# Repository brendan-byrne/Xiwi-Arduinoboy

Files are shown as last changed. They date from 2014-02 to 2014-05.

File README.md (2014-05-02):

## Arduinoboy - Xiwi Electronics ##

Product Page - <a href="http://xiwielectronics.com/products/arduinoboy">http://tiny.cc/gdzcbx</a><br />
Arduinoboy Google Code Page -  <a href="tiny.cc/bkz4xw">tiny.cc/bkz4xw</a>

Based on the Arduino platform, this device allows for MIDI signals to be sent and received by software such as Nanoloop, LSDJ, and mGB running on the Nintendo Gameboy.

Arduinoboy was developed and released under the GNU General Public License by Timothy Lamb in fall of 2008.



# Files #
**Arduinoboy Code** : Contains the original AB code written by Timothy Lamb. Upload/access via Arduino<br />

**Eagle Files** : Contains Eagle PCB and Schematic files for Xiwi Electronics Arduinoboy.<br />

**AB Editor - MIDI** : Max/MSP patch for altering MIDI channel information on the Arduinoboy. Requires MIDI In and Out ports on Arduinoboy.

**AB Enclosure** : Contains Adobe Illustrator vector drawing of Arduinoboy enclosure. Use file with laser cutter to fabricate enclosure.

**Arduino Boy Kit Assembly Instructions** : Instructions for assembling the kit sold through Xiwi Electronics. <a href="http://xiwielectronics.com/products/arduinoboy-kit">http://tiny.cc/5bzcbx</a>

**Bill of Materials** : All components and hardware used in construction of Xiwi Arduinoboy. Contains product numbers mostly through Mouser.

**Operational Document** : Layout of Xiwi Arduinoboy operations.

**mGB1_3_0.gb** : ROM file for mGB. Upload to Gameboy flash cartridge. Can receive MIDI note information to access Gameboy's internal synthesis chips. More documentation on Google Code page.

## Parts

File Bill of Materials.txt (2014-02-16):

#	Item		Mouser Part # / URL	Notes
----------------------------------------------------------------------------
1	ATMEGA328P	556-ATMEGA328P-PU	Burn Bootloader. Flash chip
1	6N138		859-6N138
	
1	28-pin Socket	571-1-390262-2		
1 	8-pin Socket	571-1825093-2

1	16 Mhz Crystal	559-FOXS160-20-LF
1	7805 V Reg	863-NCP7805TG

1 	1N914 Diode	512-1N914		Can be most any small signal diode

2	220 Resistor	291-220-RC
1	270 Resistor	291-270-RC
1	4.7K Resistor	291-4.7K-RC
1	2k Resistor	291-2K-RC		Pull-down Resistor. 1K+ Value
6	2.2K Resistor	291-2.2K-RC		LED Brightness. Personal Preference

6 	3mm LEDs	604-WP3A8GD		Any color

1 	1uf Capacitor	661-EKMA500ETC1R0MD0
2	22pf Capacitor	140-50N2-220J-RC

3 	MIDI Jacks	161-0504-E
1	2.1mm Jack	502-RAPC722X
1	Pushbutton	URL - bit.ly/1naxZhZ	Change Laser file to fit your button

1	MIDI Plug	171-0275
1 	DMG Link Cable	URL - bit.ly/MtgLkj

4	1/4" 4-40 Flat	URL - bit.ly/Mtf0ne	Screws for Bottomplate
4 	3/8" 4-40 Flat	URL - bit.ly/Mtf0ne	Screws for Faceplate
4	Hex Nut 4-40	URL - bit.ly/1eUcsFM	Btwn Faceplate and PCB
4	Hex Standoff	761-2108T-440-AL-7

4 	Rubber Feet	URL - bit.ly/1isiEZS

1  	Xiwi Arduinoboy PCB
1  	Xiwi Acrylic Arduinoboy Faceplate
1  	Xiwi Acrylic Arduinoboy Bottomplate

820 Ohm - Orange
10k Ohm - Blue
2K Ohm - Green

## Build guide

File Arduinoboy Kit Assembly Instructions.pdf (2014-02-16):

Arduinoboy Kit Assembly Instructions Brendan Byrne – Xiwi Electronics
GitHub Repository - http://tiny.cc/uyscbx
Product Page - http://tiny.cc/potcbx **************************************************************

Hello and thank you for purchasing an Arduinoboy kit from Xiwi Electronics. Follow the instructions listed below and you'll be making chiptunes in no time at all. Enjoy, friend.

This kit assumes you have introductory knowledge of electronic components and soldering. At the very least, you will need a soldering iron, solder, wire strippers, flush cutters, helpy hands, pliers, and Phillips head screwdriver.

It is recommended that you reference this doc from a computer rather than printing.

For more detailed information such as PCB layout, laser cutter files, and schematics, please refer to the GitHub Link at the top of this document.

For questions or problems related to the Arduinoboy Kit you may contact me, Brendan Byrne, at xiwicontact@gmail.com. I'll do everything I can to make sure you have a fully operational unit.

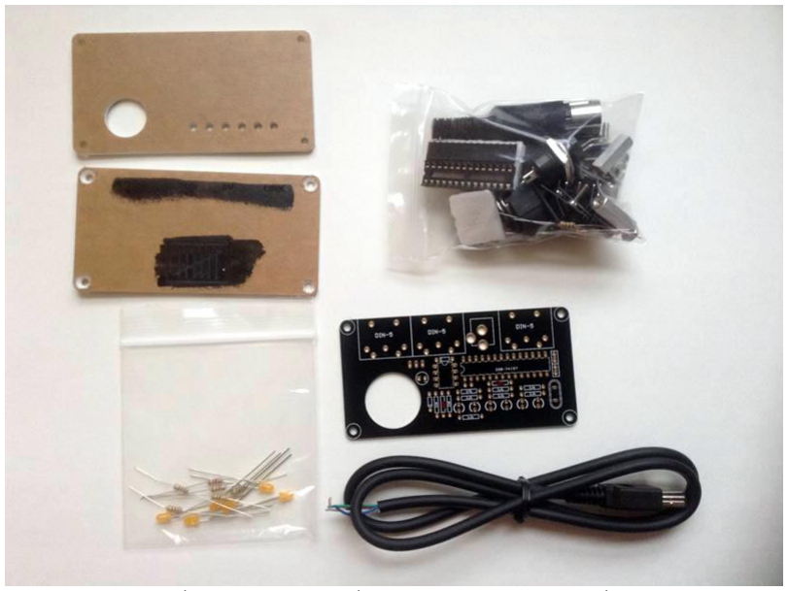
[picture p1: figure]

(Loose black wire and operational document not pictured)

Bill of Materials
**************************************************************

Main Bag:
1 – ATMEGA328 – Flashed with AB Software
1 – 6N138 Optoisolator
1 – 28 pin IC Socket
1 – 8 pin IC Socket
1 – 7805 Voltage Regulator
1 – 16 Mhz Crystal
2 – 220 Ohm Resistors (Red-Red-Brown)
1 – 4.7k Ohm Resistor (Yellow-Purple-Red) 1 – 5.6k Ohm Resistor (Green-Blue-Red) 1 – 270 Ohm Resistor (Blue one)
2 – 1N914 Diodes
1 – 1uF Capacitor
2 – 22pF Capacitors
1 – Pushbutton
3 – MIDI Connector Panel Jacks
1 – MIDI Plug
1 – 2.1mm Barrel Jack
4 – 1/4” 4-40 Flat Head Machine Screws 4 – 3/8” 4-40 Flat Head Machine Screws 4 - 4-40 Hex Nuts
4 – 25/32” Zinc Standoffs
4 – Rubber Feet

LED Bag:
6 – 3mm LEDs of Your Chosen Color
6 – Corresponding Resistors
Red | - 2k Ohm (Red-Black-Red)
Blue | - 10k Ohm (Brown-Black-Orange)
Green | - 1.2k Ohm (Brown-Red-Red)
Orange | - 820 Ohm (Grey-Red-Brown)

Loose:
1 – Arduinoboy PCB
1 – Acrylic Faceplate
1 – Acrylic Bottomplate
1 – Half of Original Gameboy DMG Link Cable 1 – Loose Black Wire
1 – Operational Document

PCB and Faceplate Assembly **************************************************************

The board is labeled with the values of resistors and their corresponding locations. However, there are two mistakes. I apologize. These locations have been marked with a red sharpie. The position marked 270 will take the 4.7k Ohm resistor and the one marked 2k will receive the 5.6k Ohm resistor. Make sure your board resembles the one pictured below.

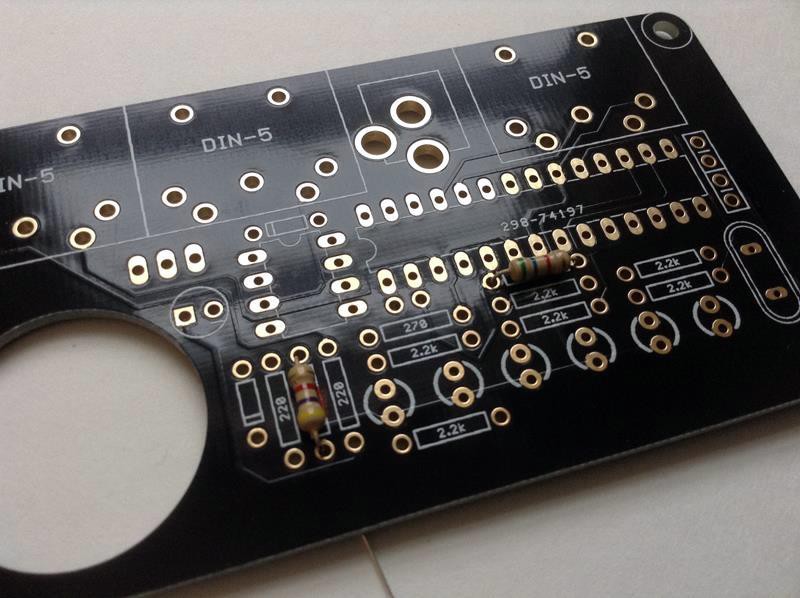
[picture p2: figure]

Following this step. You may proceed with populating the circuit board with the rest of the low level components (i.e., resistors, diodes, and the 16 Mhz crystal). The location marked “270” receives the blue resistor.

Take note that wherever you see a “2.2k” label, this is where you will place the resistors from the LED bag. In this example, I am building an orange Arduinoboy and am using 820 Ohm resistor.

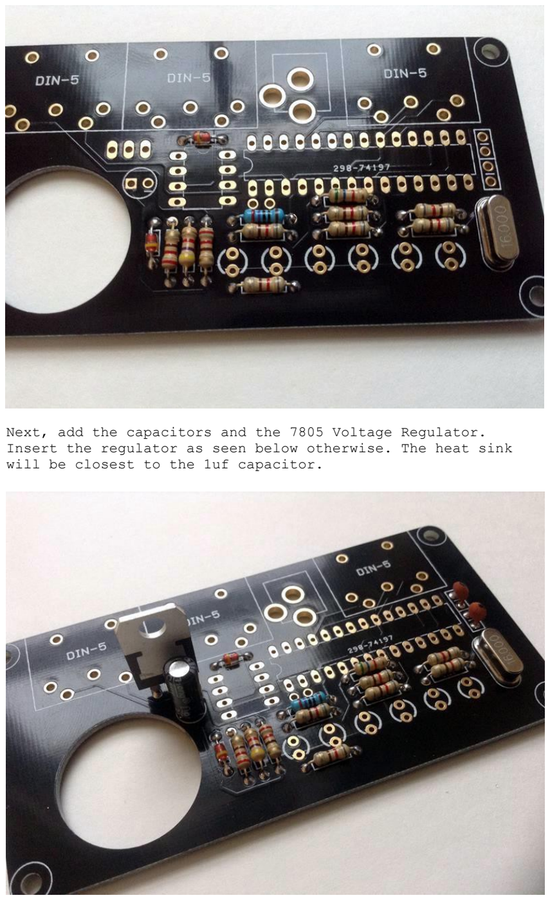
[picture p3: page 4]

Next, add the capacitors and the 7805 Voltage Regulator. Insert the regulator as seen below otherwise. The heat sink will be closest to the 1uf capacitor.

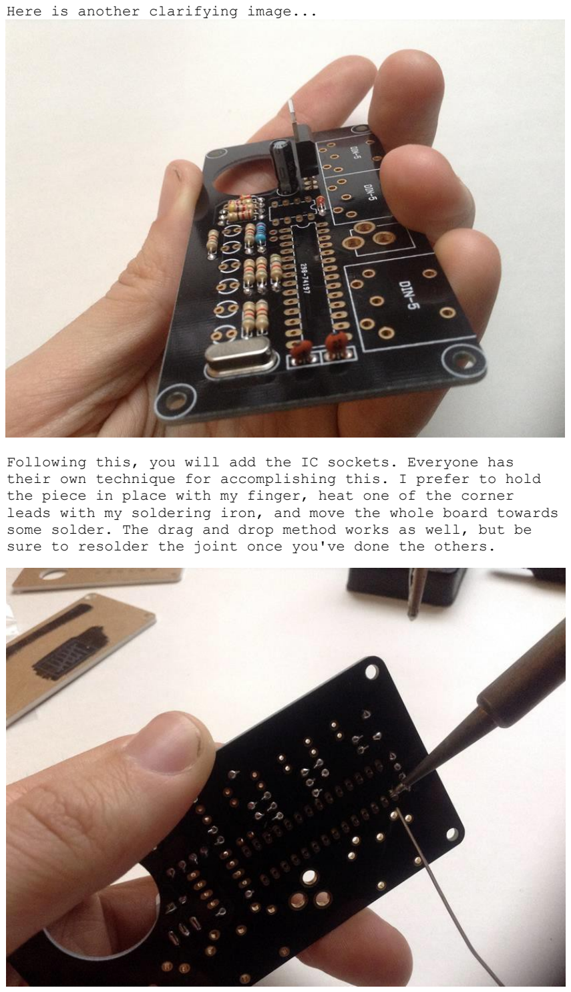
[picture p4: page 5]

Here is another clarifying image...

Following this, you will add the IC sockets. Everyone has their own technique for accomplishing this. I prefer to hold the piece in place with my finger, heat one of the corner leads with my soldering iron, and move the whole board towards some solder. The drag and drop method works as well, but be sure to resolder the joint once you've done the others.

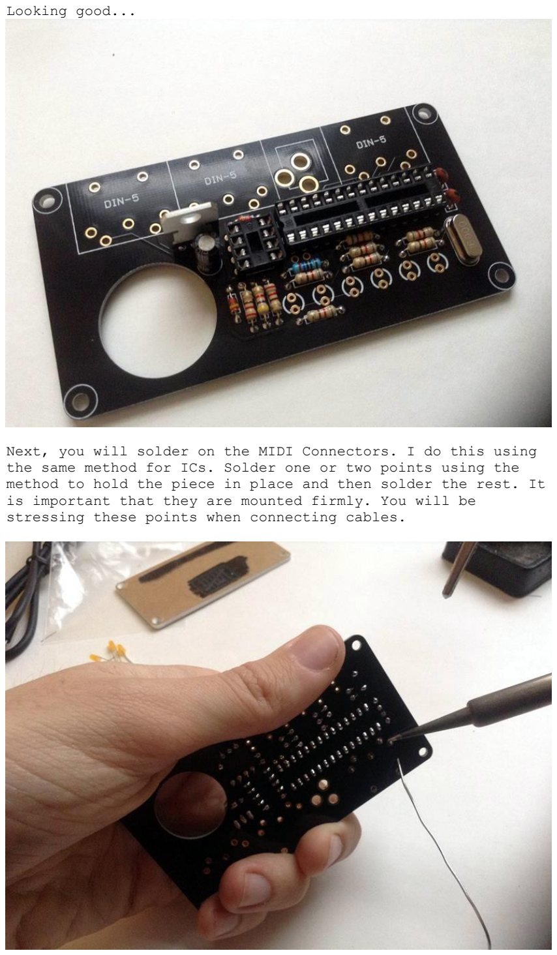
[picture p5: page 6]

Looking good...

Next, you will solder on the MIDI Connectors. I do this using the same method for ICs. Solder one or two points using the method to hold the piece in place and then solder the rest. It is important that they are mounted firmly. You will be stressing these points when connecting cables.

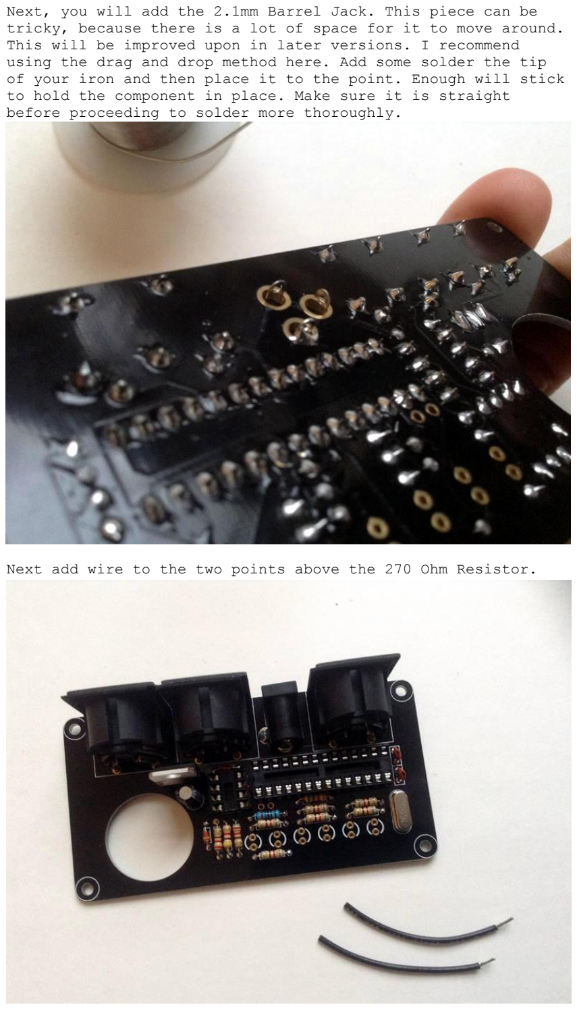
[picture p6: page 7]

Next, you will add the 2.1mm Barrel Jack. This piece can be tricky, because there is a lot of space for it to move around. This will be improved upon in later versions. I recommend using the drag and drop method here. Add some solder the tip of your iron and then place it to the point. Enough will stick to hold the component in place. Make sure it is straight before proceeding to solder more thoroughly.

Next add wire to the two points above the 270 Ohm Resistor.

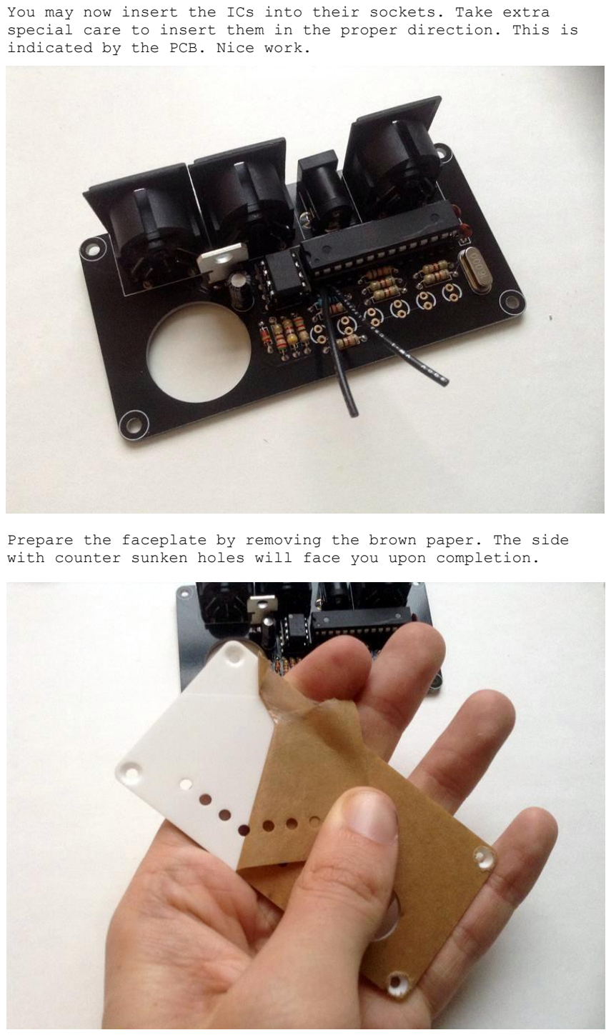
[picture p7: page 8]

You may now insert the ICs into their sockets. Take extra special care to insert them in the proper direction. This is indicated by the PCB. Nice work.

Prepare the faceplate by removing the brown paper. The side with counter sunken holes will face you upon completion.

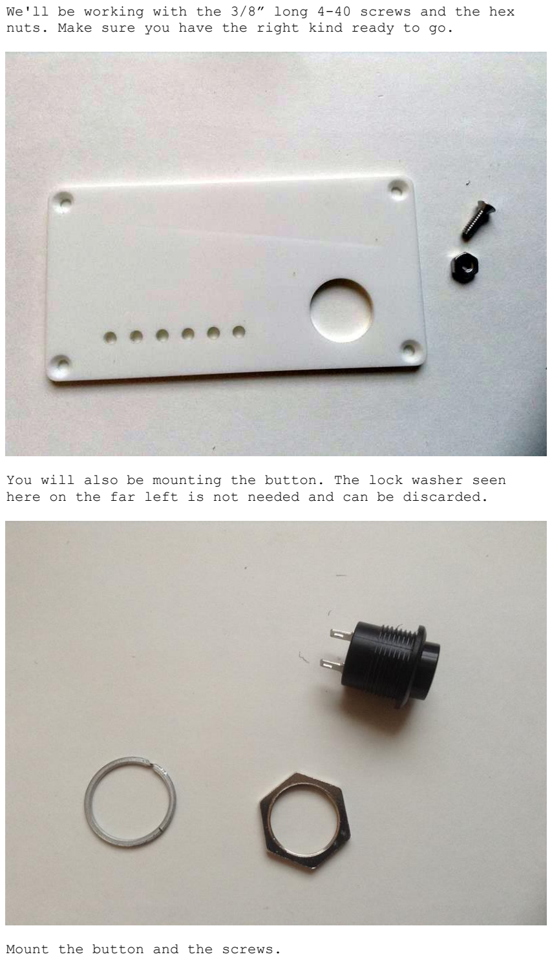
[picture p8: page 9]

We'll be working with the 3/8” long 4-40 screws and the hex nuts. Make sure you have the right kind ready to go.

You will also be mounting the button. The lock washer seen here on the far left is not needed and can be discarded.

Mount the button and the screws.

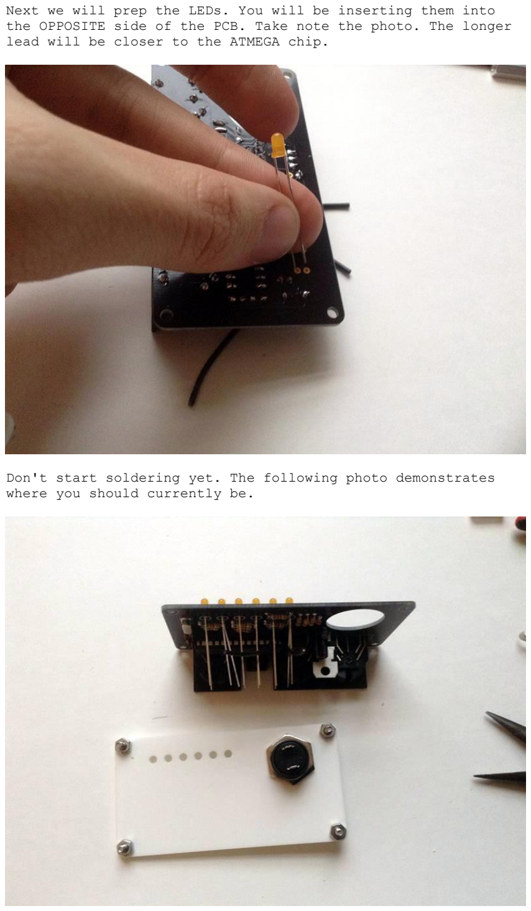
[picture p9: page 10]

Next we will prep the LEDs. You will be inserting them into the OPPOSITE side of the PCB. Take note the photo. The longer lead will be closer to the ATMEGA chip.

Don't start soldering yet. The following photo demonstrates where you should currently be.

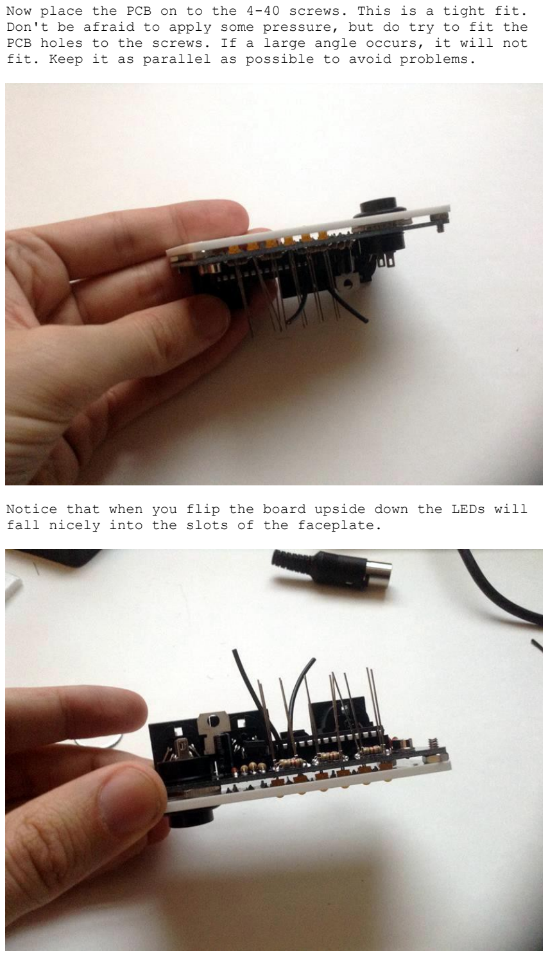
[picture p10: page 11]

Now place the PCB on to the 4-40 screws. This is a tight fit. Don't be afraid to apply some pressure, but do try to fit the PCB holes to the screws. If a large angle occurs, it will not fit. Keep it as parallel as possible to avoid problems.

Notice that when you flip the board upside down the LEDs will fall nicely into the slots of the faceplate.

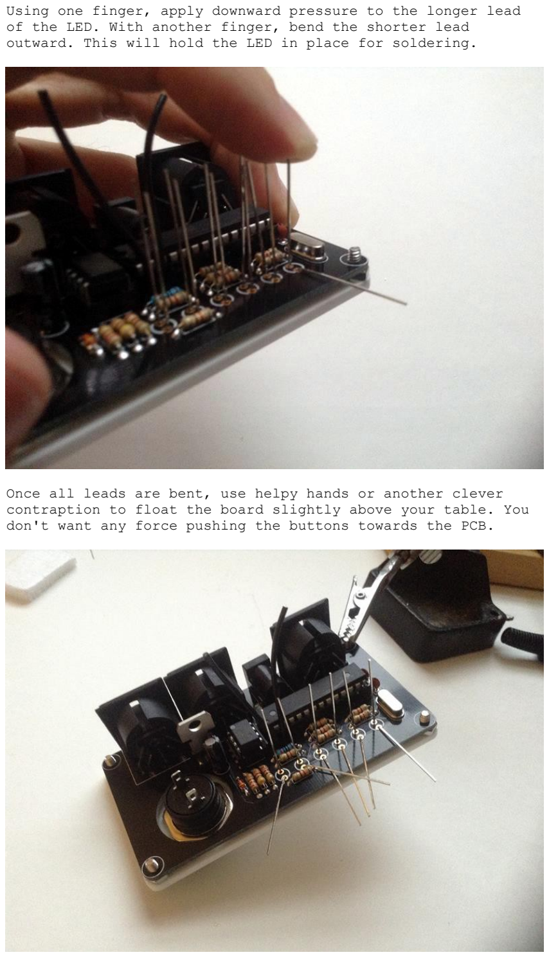
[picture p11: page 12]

Using one finger, apply downward pressure to the longer lead of the LED. With another finger, bend the shorter lead outward. This will hold the LED in place for soldering.

Once all leads are bent, use helpy hands or another clever contraption to float the board slightly above your table. You don't want any force pushing the buttons towards the PCB.

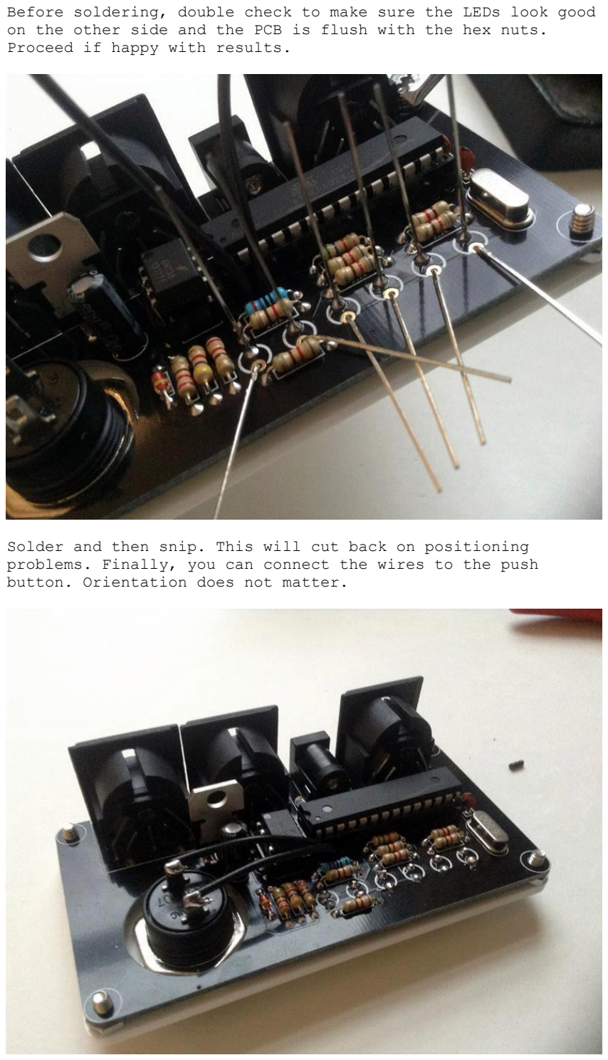
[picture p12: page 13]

Before soldering, double check to make sure the LEDs look good on the other side and the PCB is flush with the hex nuts. Proceed if happy with results.

Solder and then snip. This will cut back on positioning problems. Finally, you can connect the wires to the push button. Orientation does not matter.

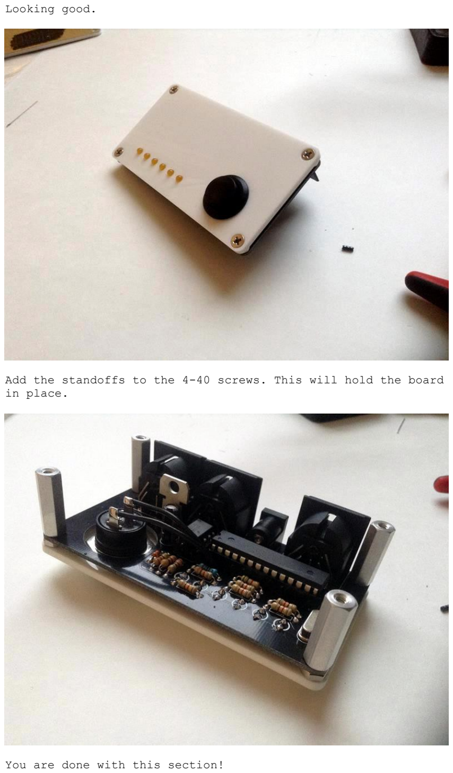
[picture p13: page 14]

Looking good.

Add the standoffs to the 4-40 screws. This will hold the board in place.

You are done with this section!

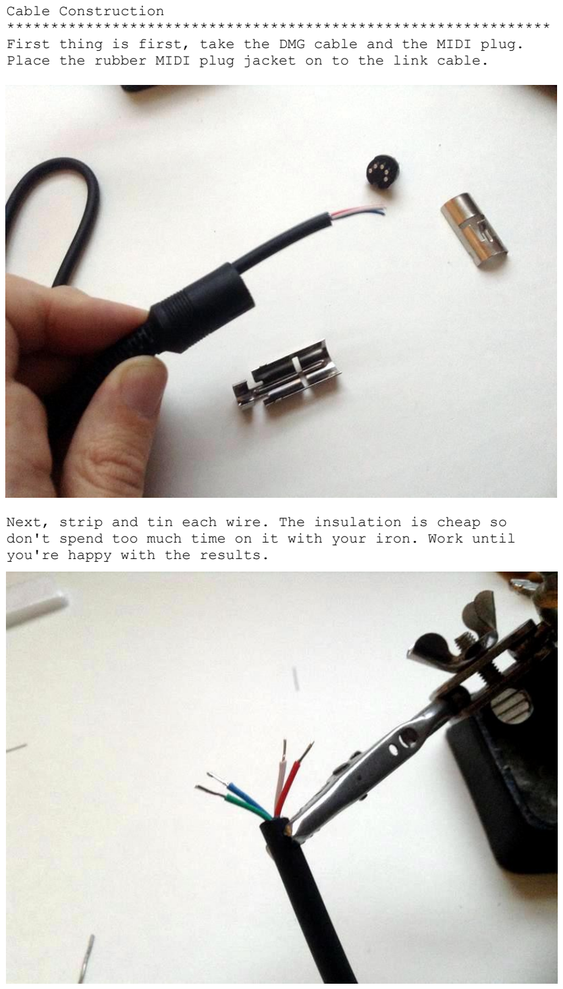
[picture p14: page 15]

Cable Construction
************************************************************** First thing is first, take the DMG cable and the MIDI plug. Place the rubber MIDI plug jacket on to the link cable.

Next, strip and tin each wire. The insulation is cheap so don't spend too much time on it with your iron. Work until you're happy with the results.

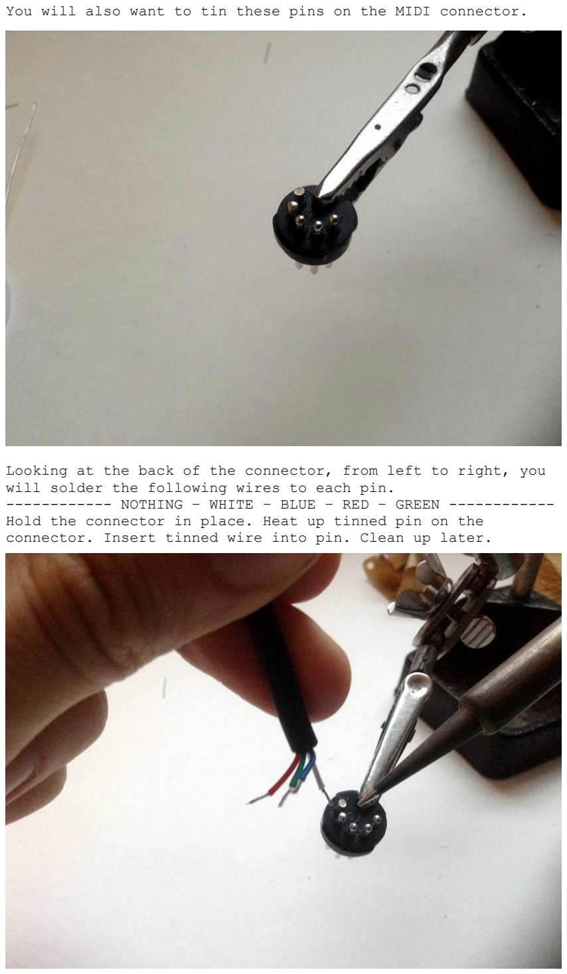
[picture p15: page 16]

You will also want to tin these pins on the MIDI connector.

Looking at the back of the connector, from left to right, you will solder the following wires to each pin.
------------ NOTHING – WHITE – BLUE – RED – GREEN ------------Hold the connector in place. Heat up tinned pin on the connector. Insert tinned wire into pin. Clean up later.

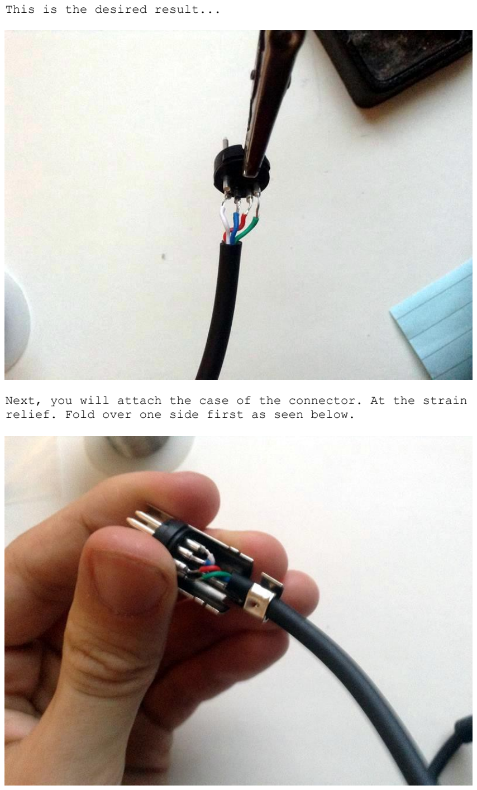
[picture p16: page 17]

This is the desired result...

Next, you will attach the case of the connector. At the strain relief. Fold over one side first as seen below.

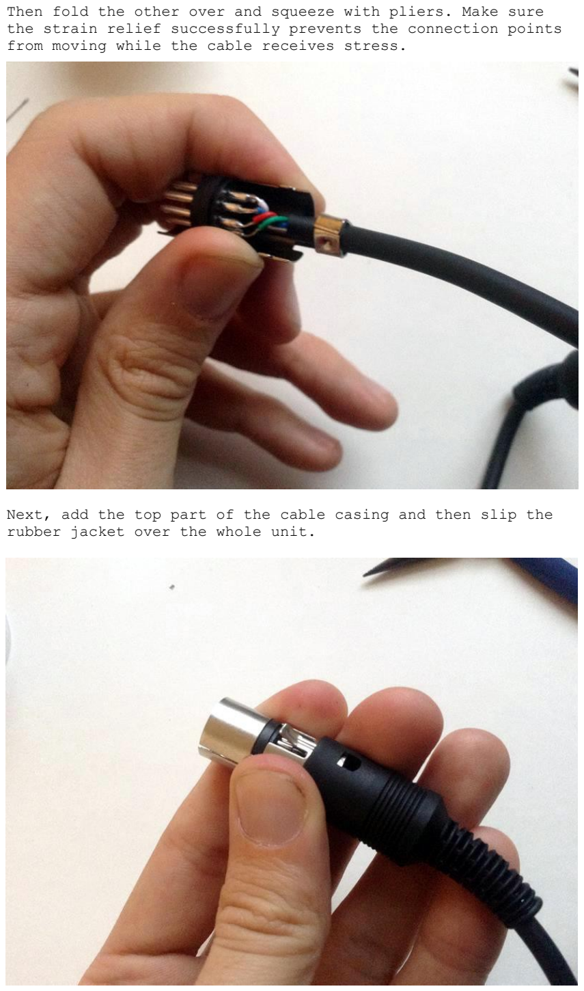
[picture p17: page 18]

Then fold the other over and squeeze with pliers. Make sure the strain relief successfully prevents the connection points from moving while the cable receives stress.

Next, add the top part of the cable casing and then slip the rubber jacket over the whole unit.

You've completed this portion!

At this point it is recommended that you power on your Arduinoboy and connect it to your Gameboy. Run some test MIDI information into or out of it and see if it is working properly. Refer to the Arduinoboy documentation on the Google code page for proper operation code.google.com/p/arduinoboy/

If you suspect your Arduinoboy isn't functioning properly, return to the circuit and perform basic troubleshooting to discover the problem. You may also want to refer to a schematic and the board layout. These can be found on the GitHub page. http://tiny.cc/uyscbx

If it's working properly, then proceed with instructions...

************************************************************** Finishing Touches
************************************************************** Remove the protective paper from the acrylic bottomplate. You can use your fingernail to remove the small pieces of paper without fear of damaging or scratching the surface.

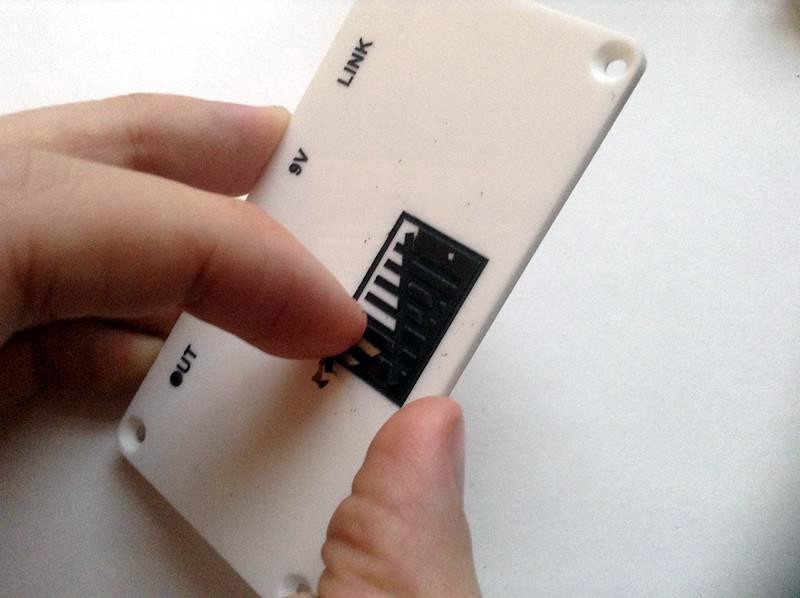
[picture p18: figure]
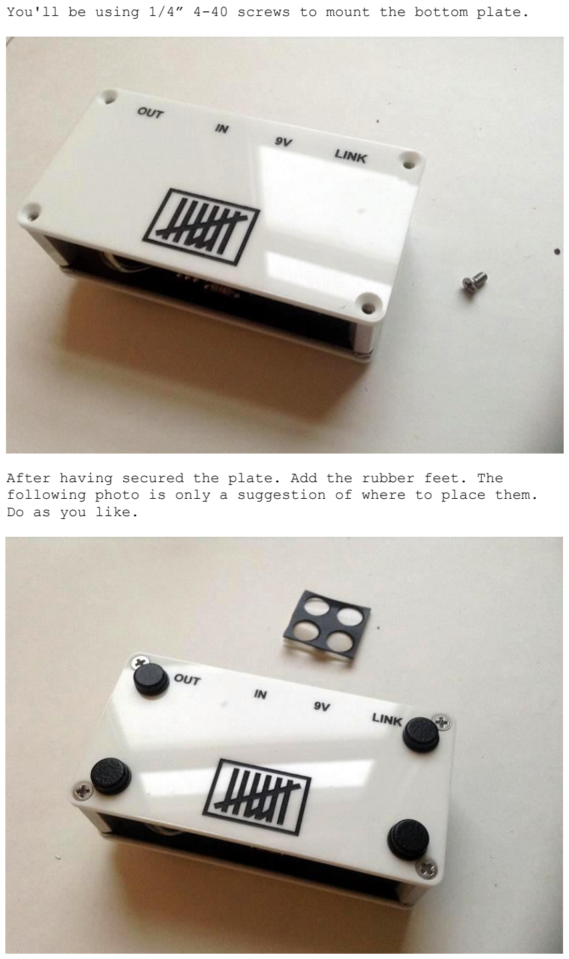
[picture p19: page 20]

You'll be using 1/4” 4-40 screws to mount the bottom plate.

After having secured the plate. Add the rubber feet. The following photo is only a suggestion of where to place them. Do as you like.

Congratulations. You are now the proud owner of a totally awesome device for making killer music and you built it yourself. High five!

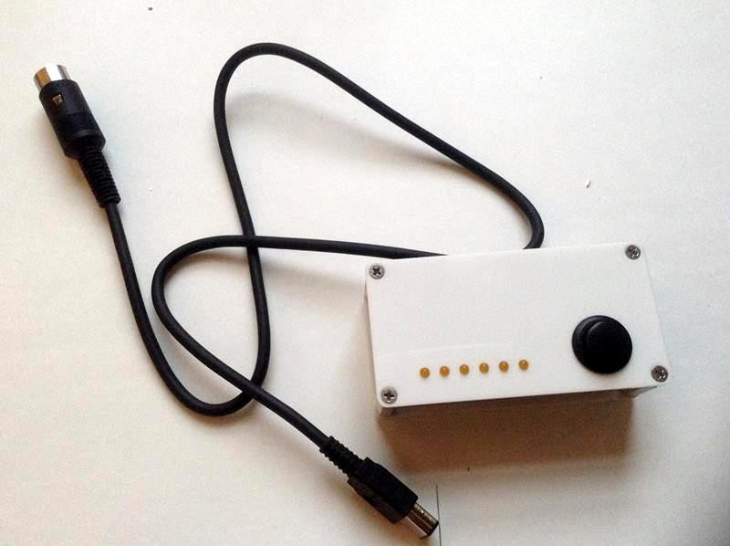
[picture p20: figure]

Thank you.

Follow me on...
twitter - @bigwetdognose (https://twitter.com/bigwetdognose)
tumblr – wtfbyrne.tumlblr.com (http://wtfbyrne.tumblr.com/)

Send chip jams/photos of your AB. Will retweet.

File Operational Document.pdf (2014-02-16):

# Arduinoboy from Xiwi Electronics

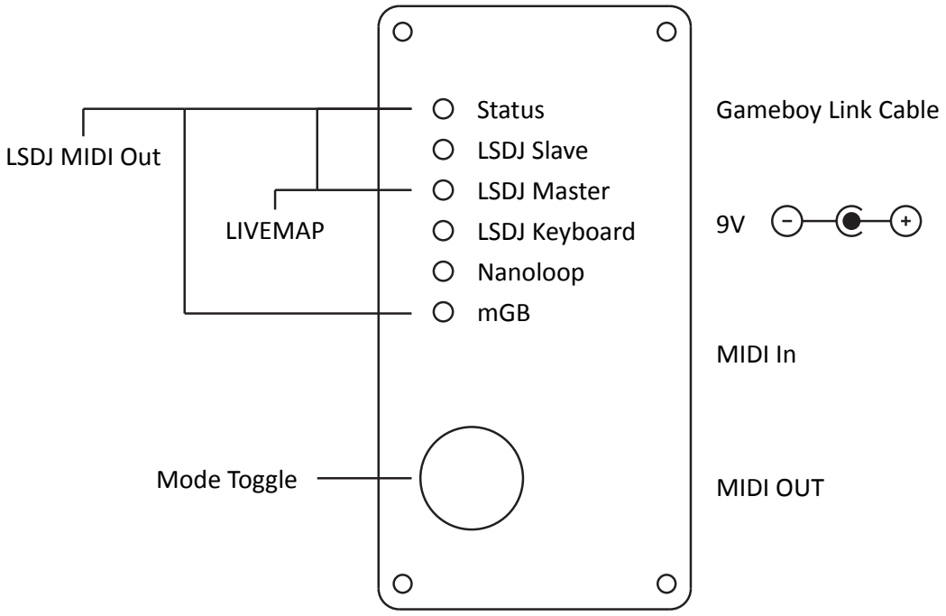
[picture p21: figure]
Status; Gameboy Link Cable; MIDI In; MIDI OUT; LSDJ Slave; Nanoloop mGB; LSDJ Master; LIVEMAP; LSDJ Keyboard; LSDJ MIDI Out; Mode Toggle

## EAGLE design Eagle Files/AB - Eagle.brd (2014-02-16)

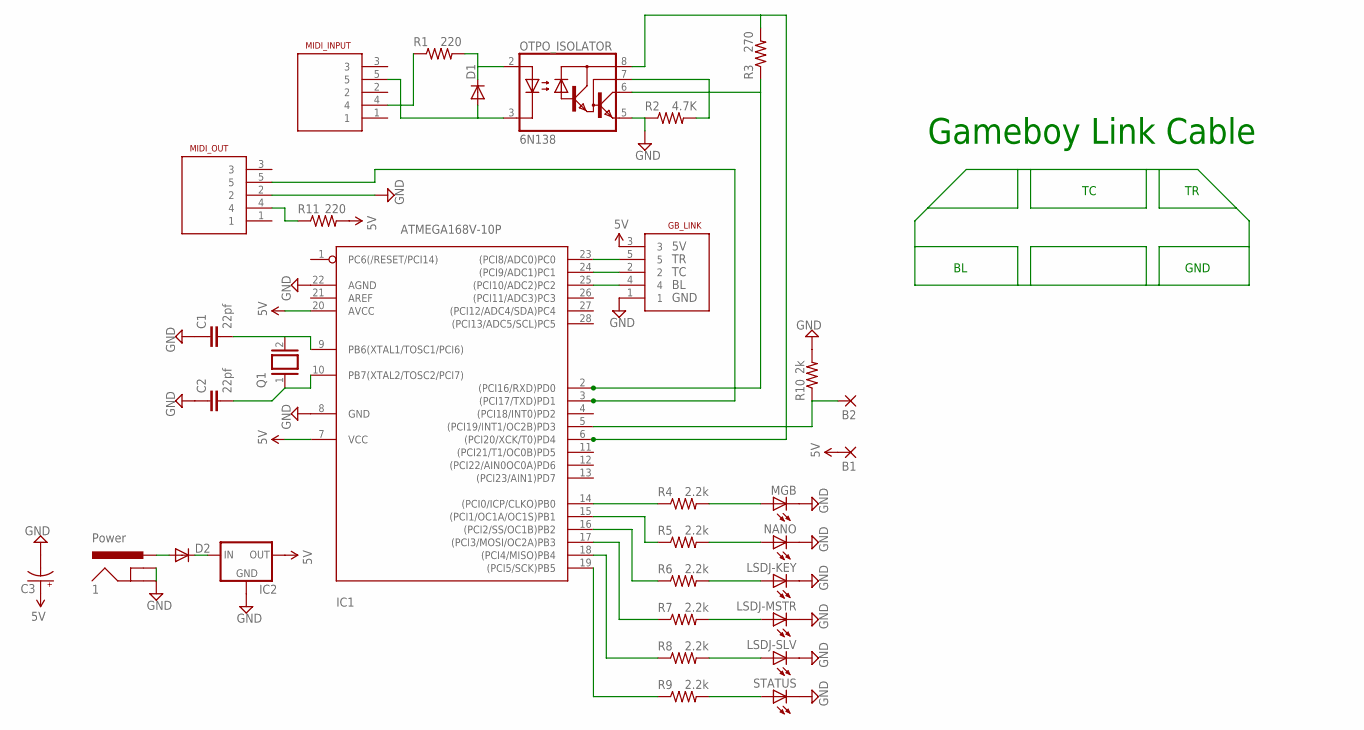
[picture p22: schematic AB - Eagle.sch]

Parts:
1: Power; POWER_JACK_PTH
B1, B2: 2,15/1,0
C1, C2: 22pf; CAP-PTH-SMALL2
C3: CAP_POLPTH2; CPOL-RADIAL-10UF-25V
D1, D2: DIODE1N4148; DIODE-1N4148
GB_LINK: MIDI_CONN_FEMALE_SUPPORT; DIN_5_FEMALE_SUPPORT
IC1: ATMEGA168V-10P; DIL28-3
IC2: V_REG_78XX-TO-220; TO-220-ALT
LSDJ-KEY: LED3MM
LSDJ-MSTR: LED3MM
LSDJ-SLV: LED3MM
MGB: LED3MM
MIDI_INPUT: MIDI_CONN_FEMALE_SUPPORT; DIN_5_FEMALE_SUPPORT
MIDI_OUT: MIDI_CONN_FEMALE_SUPPORT; DIN_5_FEMALE_SUPPORT
NANO: LED3MM
OTPO_ISOLATOR: 6N138; DIL08
Q1: XTAL/S; QS
R1, R11: 220; AXIAL-0.3
R2: 4.7K; AXIAL-0.3
R3: 270; AXIAL-0.3
R4, R5, R6, R7, R8, R9: 2.2k; AXIAL-0.3
R10: 2k; AXIAL-0.3
STATUS: LED3MM

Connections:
5V: B1.1, C3.1 (+), GB_LINK.3, IC1.7 (VCC), IC1.20 (AVCC), IC2.OUT, R11.P$2 (2)
GND: 1.GND, 1.GNDBREAK, C1.1, C2.1, C3.2 (-), GB_LINK.1, IC1.8 (GND), IC1.22 (AGND), IC2.GND, LSDJ-KEY.K (C), LSDJ-MSTR.K (C), LSDJ-SLV.K (C), MGB.K (C), MIDI_OUT.2, NANO.K (C), OTPO_ISOLATOR.5 (GND), R2.P$1 (1), R10.P$2 (2), STATUS.K (C)
unnamed: D1.C, OTPO_ISOLATOR.2 (A), R1.P$2 (2)
unnamed: IC1.14 ((PCI0/ICP/CLKO)PB0), R4.P$1 (1)
unnamed: GB_LINK.5, IC1.23 ((PCI8/ADC0)PC0)
unnamed: B2.1, IC1.5 ((PCI19/INT1/OC2B)PD3), R10.P$1 (1)
unnamed: IC1.15 ((PCI1/OC1A/OC1S)PB1), R5.P$1 (1)
unnamed: IC1.16 ((PCI2/SS/OC1B)PB2), R6.P$1 (1)
unnamed: IC1.17 ((PCI3/MOSI/OC2A)PB3), R7.P$1 (1)
unnamed: IC1.18 ((PCI4/MISO)PB4), R8.P$1 (1)
unnamed: OTPO_ISOLATOR.7 (VB), R2.P$2 (2)
unnamed: IC1.19 ((PCI5/SCK)PB5), R9.P$1 (1)
unnamed: IC1.2 ((PCI16/RXD)PD0), OTPO_ISOLATOR.6 (VO), R3.P$1 (1)
unnamed: MGB.A, R4.P$2 (2)
unnamed: NANO.A, R5.P$2 (2)
unnamed: LSDJ-KEY.A, R6.P$2 (2)
unnamed: LSDJ-MSTR.A, R7.P$2 (2)
unnamed: LSDJ-SLV.A, R8.P$2 (2)
unnamed: R9.P$2 (2), STATUS.A
unnamed: C2.2, IC1.10 (PB7(XTAL2/TOSC2/PCI7)), Q1.1
unnamed: C1.2, IC1.9 (PB6(XTAL1/TOSC1/PCI6)), Q1.2
unnamed: GB_LINK.2, IC1.24 ((PCI9/ADC1)PC1)
unnamed: GB_LINK.4, IC1.25 ((PCI10/ADC2)PC2)
unnamed: 1.PWR, D2.A
unnamed: D2.C, IC2.IN
unnamed: MIDI_INPUT.4, R1.P$1 (1)
unnamed: D1.A, MIDI_INPUT.5, OTPO_ISOLATOR.3 (C)
unnamed: MIDI_OUT.4, R11.P$1 (1)
unnamed: IC1.6 ((PCI20/XCK/T0)PD4), OTPO_ISOLATOR.8 (VCC), R3.P$2 (2)
TXOUT: IC1.3 ((PCI17/TXD)PD1), MIDI_OUT.5

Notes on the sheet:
GND
Gameboy Link Cable

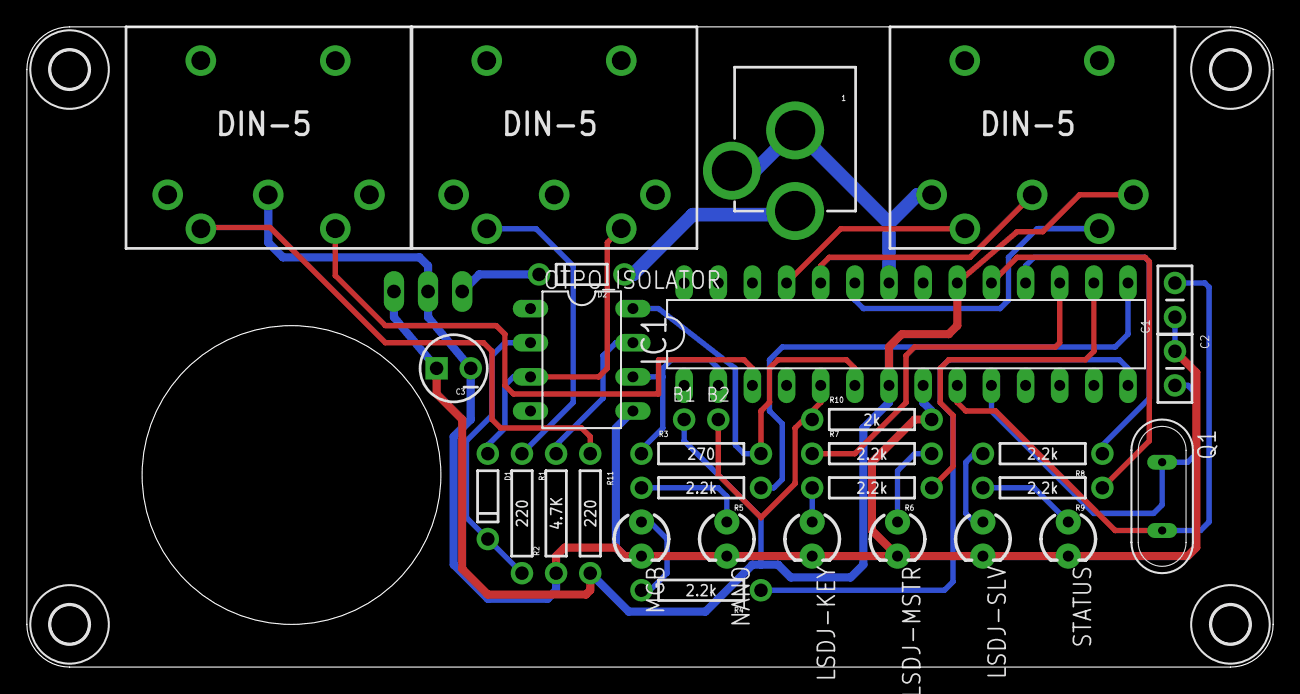
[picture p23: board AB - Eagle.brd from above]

Board: 2 copper layers, 92.7 x 47.6 mm, 36 parts (0 on the bottom side), 30 nets.

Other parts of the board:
U$2, U$3, U$4, U$5: 2,8

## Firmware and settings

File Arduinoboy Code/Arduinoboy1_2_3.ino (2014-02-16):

/***************************************************************************
 ***************************************************************************
 *                         __      _             __                        *
 *         ____ __________/ /_  __(_)___  ____  / /_  ____  __  __         *
 *        / __ `/ ___/ __  / / / / / __ \/ __ \/ __ \/ __ \/ / / /         *
 *       / /_/ / /  / /_/ / /_/ / / / / / /_/ / /_/ / /_/ / /_/ /          *
 *       \__,_/_/   \__,_/\__,_/_/_/ /_/\____/_.___/\____/\__, /           *
 *                                                       /____/            *
 *                                                                         *
 ***************************************************************************
 ***************************************************************************
 *                                                                         *
 * Version: 1.2.2                                                          *
 * Date:    Sept 14 2011                                                     *
 * Name:    Timothy Lamb                                                   *
 * Email:   trash80@gmail.com                                              *
 *                                                                         *
 ***************************************************************************
 ***************************************************************************
 *                                                                         *
 * NOTICE NOTICE NOTICE NOTICE NOTICE NOTICE NOTICE NOTICE NOTICE NOTICE   *
 * NOTICE NOTICE NOTICE NOTICE NOTICE NOTICE NOTICE NOTICE NOTICE NOTICE   *
 * NOTICE NOTICE NOTICE NOTICE NOTICE NOTICE NOTICE NOTICE NOTICE NOTICE   *
 * NOTICE NOTICE NOTICE NOTICE NOTICE NOTICE NOTICE NOTICE NOTICE NOTICE   *
 * NOTICE NOTICE NOTICE NOTICE NOTICE NOTICE NOTICE NOTICE NOTICE NOTICE   *
 *                                                                         *
 *  As of version 1.1.0 Gameboy Pins have changes from 5,6,7 to Analog in  *
 *  pins 0,1,2 ... This allows direct port access which not interfearing   *
 *  with serial communication. There are no more "delay" settings, and     * 
 *  everything seems much faster / better now.                             *
 *                                                                         *
 *  http://code.google.com/p/arduinoboy/                                   *
 *                                                                         *
 *   Arduino pin settings:  (Layout is final)                              *
 *     - 6 LEDS on pins 8 to 13                                            *
 *     - Push button on pin 3 (for selecting mode)                         *
 *     - MIDI Opto-isolator power on pin 4                                 *
 *     - Gameboy Clock line on analog in pin 0                             *
 *     - Gameboy Serial Data input on analog in pin 1                      *
 *     - Serial Data from gameboy on analog in pin 2                       *
 *                                                                         *
 * Program Information:                                                    *
 *    LSDJ Slave Mode Midi Note Effects:                                   *
 *      48 - C-2 Sends a Sequencer Start Command                           *
 *      49 - C#2 Sends a Sequencer Stop Command                            *
 *      50 - D-2 Toggles Normal Tempo                                      *
 *      51 - D#2 Toggles 1/2 Tempo                                         *
 *      52 - E-2 Toggles 1/4 Tempo                                         *
 *      53 - F-2 Toggles 1/8 Tempo                                         *
 *                                                                         *
 *    LSDJ Keyboard Mode:                                                  *
 *      48 - C-2 Mute Pu1 Off/On                                           *
 *      49 - C#2 Mute Pu2 Off/On                                           *
 *      50 - D-2 Mute Wav Off/On                                           *
 *      51 - D#2 Mute Noi Off/On                                           *
 *      52 - E-2 Livemode Cue Sequence                                     *
 *      53 - F-2 Livemode Cursor Up                                        *
 *      54 - F#2 Livemode Cursor Down                                      *
 *      55 - G-2 Livemode Cursor Left                                      *
 *      56 - G#2 Livemode Cursor Right                                     *
 *      57 - A-2 Table Up                                                  *
 *      58 - A#2 Table Down                                                *
 *      59 - B-2 Cue Table                                                 *
 *      60 - C-3 to C-8 Notes!                                             *
 *      Prgram Change to select from instrument table                      *
 *                                                                         *
 ***************************************************************************/
/***************************************************************************
 *                                                                         *
 *   This program is free software; you can redistribute it and/or modify  *
 *   it under the terms of the GNU General Public License as published by  *
 *   the Free Software Foundation; either version 2 of the License, or     *
 *   (at your option) any later version.                                   *
 *                                                                         *
 ***************************************************************************/
#include <EEPROM.h>
#define MEM_MAX 65
#define NUMBER_OF_MODES 7    //Right now there are 7 modes, Might be more in the future

//!!! do not edit these, they are the position in EEPROM memory that contain the value of each stored setting
#define MEM_CHECK 0
#define MEM_VERSION_FIRST 1
#define MEM_VERSION_SECOND 2
#define MEM_MODE 5
#define MEM_FORCE_MODE 4

#define MEM_LSDJSLAVE_MIDI_CH 6

#define MEM_LSDJMASTER_MIDI_CH 7
#define MEM_KEYBD_CH 8

#define MEM_KEYBD_COMPAT_MODE 9
#define MEM_KEYBD_CH_TO_INST 10

#define MEM_MIDIOUT_NOTE_CH 11
#define MEM_MIDIOUT_CC_CH 15
#define MEM_MIDIOUT_CC_MODE 19
#define MEM_MIDIOUT_CC_SCALING 23
#define MEM_MIDIOUT_CC_NUMBERS 27

#define MEM_MGB_CH 55
#define MEM_LIVEMAP_CH 60

#define MEM_MIDIOUT_BIT_DELAY 61
#define MEM_MIDIOUT_BYTE_DELAY 63



/***************************************************************************
* User Settings
***************************************************************************/

boolean alwaysUseDefaultSettings = false; //set to true to always use the settings below, else they are pulled from memory for the software editor


boolean usbMode                  = false; //to use usb for serial communication as oppose to MIDI - sets baud rate to 38400


byte defaultMemoryMap[MEM_MAX] = {
  0x7F,0x01,0x02,0x7F, //memory init check
  0x00, //force mode (forces lsdj to be sl)
  0x00, //mode
  
  15, //sync effects midi channel (0-15 = 1-16)
  15, //masterNotePositionMidiChannel - LSDJ in master mode will send its song position on the start button via midi note. (0-15 = 1-16)
  
  15, //keyboardInstrumentMidiChannel - midi channel for keyboard instruments in lsdj. (0-15 = 1-16)
  1, //Keyboard Compatability Mode
  1, //Set to true if you want to have midi channel set the instrument number / doesnt do anything anymore
  
  0,1,2,3, //midiOutNoteMessageChannels - midi channels for lsdj midi out note messages Default: channels 1,2,3,4
  0,1,2,3, //midiOutCCMessageChannels - midi channels for lsdj midi out CC messages Default: channels 1,2,3,4
  1,1,1,1, //midiOutCCMode - CC Mode, 0=use 1 midi CC, with the range of 00-6F, 1=uses 7 midi CCs with the
                       //range of 0-F (the command's first digit would be the CC#), either way the value is scaled to 0-127 on output
  1,1,1,1, //midiOutCCScaling - CC Scaling- Setting to 1 scales the CC value range to 0-127 as oppose to lsdj's incomming 00-6F (0-112) or 0-F (0-15) 
  1,2,3,7,10,11,12, //pu1: midiOutCCMessageNumbers - CC numbers for lsdj midi out, if CCMode is 1, all 7 ccs are used per channel at the cost of a limited resolution of 0-F
  1,2,3,7,10,11,12, //pu2
  1,2,3,7,10,11,12, //wav
  1,2,3,7,10,11,12, //noi
  
  0, 1, 2, 3, 4, //mGB midi channels (0-15 = 1-16)
  15, //livemap / sync map midi channel (0-15 = 1-16)
  80,1,  //midiout bit check delay & bit check delay multiplier 
  0,0//midiout byte received delay & byte received delay multiplier 
};
byte memory[MEM_MAX];

/***************************************************************************
* Lets Assign our Arduino Pins .....
***************************************************************************/

int pinGBClock     = 0;    // Analog In 0 - clock out to gameboy
int pinGBSerialOut = 1;    // Analog In 1 - serial data to gameboy
int pinGBSerialIn  = 2;    // Analog In 2 - serial data from gameboy

int pinMidiInputPower = 4; // power pin for midi input opto-isolator

int pinStatusLed = 13; // Status LED
int pinLeds[] = {12,11,10,9,8,13}; // LED Pins

int pinButtonMode = 3; //toggle button for selecting the mode

/***************************************************************************
* Memory
***************************************************************************/

int eepromMemoryByte = 0; //Location of where to store settings from mem



/***************************************************************************
* Sysex Settings & vars
***************************************************************************/

boolean sysexReceiveMode = 0;
boolean sysexProgrammingMode = 0;
boolean sysexProgrammingWaiting = 0;
boolean sysexProgrammingConnected = 0;

unsigned long sysexProgrammerWaitTime = 2000; //2 seconds
unsigned long sysexProgrammerCallTime = 1000; //1 second
unsigned long sysexProgrammerLastResponse = 0;
unsigned long sysexProgrammerLastSent = 0;

byte sysexManufacturerId = 0x69; //har har harrrrr :)
int sysexPosition;
byte sysexData[128];
byte longestSysexMessage = 128;

int midioutBitDelay = 0;
int midioutByteDelay = 0;


/***************************************************************************
* Switches and states
***************************************************************************/
boolean sequencerStarted = false;        //Sequencer has Started
boolean midiSyncEffectsTime = false;
boolean midiNoteOnMode   =false;
boolean midiNoteOffMode  =false;
boolean midiProgramChange=false;
boolean midiAddressMode  =false;
boolean midiValueMode    =false;

int midiOutLastNote[4] = {-1,-1,-1,-1};

boolean statusLedIsOn    =false;
boolean statusLedBlink   =false;

boolean nanoState        =false;
boolean nanoSkipSync     =false;

int buttonDepressed;
int buttonState;
unsigned long int buttonProgrammerWaitTime = 2000; //2 whole seconds
unsigned long int buttonTime;


boolean blinkSwitch[6];
unsigned long int blinkSwitchTime[6];
int switchLight = 0;

int blinkMaxCount = 1000;

unsigned long midioutNoteTimer[4];
byte midioutNoteHold[4][4];
byte midioutNoteHoldCounter[4];
int midioutNoteTimerThreshold = 10;

/***************************************************************************
* Counter vars
***************************************************************************/
int countLSDJTicks = 0;            //for loop int (we need to cycle 8 pulses)
int countSyncTime  = 0;
int countSyncLightTime=0;
int countSyncSteps = 0;
int countSyncPulse = 0;
int countGbClockTicks =0;
int countClockPause =0;
int countIncommingMidiByte =0;
int countStatusLedOn =0;
unsigned int waitClock =0;


int miscLastLed;
unsigned long int miscLedTime;
unsigned long int miscLedMaxTime;

/***************************************************************************
* Inbound Data Placeholders
***************************************************************************/
byte incomingMidiByte;  //incomming midi message
byte readgbClockLine;
byte readGbSerialIn;
byte bit;
byte midiData[] = {0, 0, 0};
byte lastMidiData[] = {0, 0, 0};

int incomingMidiNote = 0;
int incomingMidiVel = 0;
byte readToggleMode;
byte serialWriteBuffer[256];
byte midiDefaultStartOffset;
int  writePosition=0;
int  readPosition=0;
int lastMode=0; //Stores the last selected mode for leds.

byte midiSyncByte;
byte midiSyncByteLast;

byte midiStatusType;
byte midiStatusChannel;

/***************************************************************************
* LSDJ Keyboard mode settings
***************************************************************************/      
byte keyboardNotes[] = {0x1A,0x1B,0x22,0x23,0x21,0x2A,0x34,0x32,0x33,0x31,0x3B,0x3A,
                         0x15,0x1E,0x1D,0x26,0x24,0x2D,0x2E,0x2C,0x36,0x35,0x3D,0x3C};
byte keyboardOctDn = 0x05;
byte keyboardOctUp = 0x06;

byte keyboardInsDn = 0x04;
byte keyboardInsUp = 0x0C;

byte keyboardTblDn = 0x03;
byte keyboardTblUp = 0x0B;

byte keyboardTblCue= 0x29;

byte keyboardMut1 = 0x01;
byte keyboardMut2 = 0x09;
byte keyboardMut3 = 0x78;
byte keyboardMut4 = 0x07;

byte keyboardCurL = 0x6B;
byte keyboardCurR = 0x74;
byte keyboardCurU = 0x75;
byte keyboardCurD = 0x72;
byte keyboardPgUp = 0x7D;
byte keyboardPgDn = 0x7A;
byte keyboardEntr = 0x5A;

int keyboardCurrentOct = 0;
int keyboardCurrentIns = 0;
int keyboardCurrentTbl = 0;

int keyboardLastOct = 0;
int keyboardLastIns = 0;
int keyboardLastTbl = 0;

int keyboardDiff = 0;
int keyboardCount = 0;
byte keyboardStartOctave = 0x24;
byte keyboardNoteStart = 0;
byte keyboardNoteOffset = 0;
byte keyboardCommands[12];

void setup() {
/*
  Init Memory
*/
  initMemory(0);
/*
  Init Pins
*/
  for(int led=0;led<=5;led++) pinMode(pinLeds[led],OUTPUT);
  pinMode(pinStatusLed,OUTPUT);
  pinMode(pinButtonMode,INPUT); 
  DDRC = B00111111; //Set analog in pins as outputs
  
/*
  Set MIDI Serial Rate
*/
  if(usbMode == true) {
    Serial.begin(38400); //31250
  } else {
    pinMode(pinMidiInputPower,OUTPUT); 
    digitalWrite(pinMidiInputPower,HIGH); // turn on the optoisolator
    Serial.begin(31250); //31250
  }
/*
  Set Pin States
*/
  digitalWrite(pinGBClock,HIGH);    // gameboy wants a HIGH line
  digitalWrite(pinGBSerialOut,LOW);    // no data to send
/*
  Misc Startup
*/
  keyboardNoteStart = keyboardStartOctave + 12; // Set the octave where the actual notes start (the octave below is for the mutes, cursor, etc)
/*
  Assign the keyboard mode command array for the first octave
*/
  keyboardCommands[0] = keyboardMut1;
  keyboardCommands[1] = keyboardMut2;
  keyboardCommands[2] = keyboardMut3;
  keyboardCommands[3] = keyboardMut4;
  keyboardCommands[4] = keyboardCurL;
  keyboardCommands[5] = keyboardCurR;
  keyboardCommands[6] = keyboardCurU;
  keyboardCommands[7] = keyboardCurD;
  keyboardCommands[8] = keyboardEntr;
  keyboardCommands[9] = keyboardTblDn;
  keyboardCommands[10] = keyboardTblUp;
  keyboardCommands[11] = keyboardTblCue;
/*
  Load Settings from EEPROM
*/
  if(!memory[MEM_FORCE_MODE]) memory[MEM_MODE] = EEPROM.read(MEM_MODE);
  lastMode = memory[MEM_MODE];
  
  startupSequence();
  
  showSelectedMode(); //Light up the LED that shows which mode we are in.
}

/*
  Main Loop, which we don't use to be able to isolate each mode into its own setup and loop functions
*/
void loop () {
  setMode();
  switchMode();
}

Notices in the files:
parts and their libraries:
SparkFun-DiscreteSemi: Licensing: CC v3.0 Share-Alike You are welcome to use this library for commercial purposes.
